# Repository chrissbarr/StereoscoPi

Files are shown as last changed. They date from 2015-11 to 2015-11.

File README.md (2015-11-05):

# StereoscoPi
StereoscoPi is a PCB that connects to a Raspberry Pi Compute Module. It powers the Compute Module, and provides connections for two cameras, along with a USB connection for a WiFi adaptor.

## Power
Power input is via a 2.1mm barrel jack. StereoscoPi uses a highly efficient switching regulator, and can accept 5V - 17V.

## Cameras
StereoscoPi is designed to work with the improved Raspberry Pi camera boards developed by [ArduCam](http://www.arducam.com/raspberry-pi-camera-rev-c-improves-optical-performance/). The connectors used are compatible with the standard Raspberry Pi camera boards, however the ArduCam boards are larger and feature different hole spacing.

## Connectivity
In order to minimise the size and weight of StereoscoPi, there is no onboard USB hub - this means only the single USB port integrated into the Broadcom SOC is available. This has been broken out to a full size USB-A socket.

Because the Raspberry Pi Compute module does not use removable storage as is the case with the other Raspberry Pi boards, it is necessary to connect the module to a computer and mount the flash memory as a mass storage device. This allows the copying over of all necessary operating system files. There is an onboard microUSB socket to facilitate this. As the Broadcom SOC only has the one USB connection, usually this connector is inactive. When the programming jumper is set appropriately, the full-size USB socket is disconnected, the microUSB socket is connected, and the board is set into programming mode.

Several additional outputs for power and PWM signals are broken out across the board. These are general purpose, but could - for example - be used to drive a small servo-based gimbal.

## Prototype
A proof-of-concept prototype has been constructed using two Raspberry Pi 2 B SBCs, and two separate wireless network adaptors. For information on replicating the hardware of this setup, follow the guide on the Prototype Hardware page. For software setup, see the Prototype Software page.

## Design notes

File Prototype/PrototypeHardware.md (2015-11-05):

# Prototype Hardware
## Electronics
### Bill of Materials
* 2x Raspberry Pi A+ / B+ / 2B
* 2x Raspberry Pi Camera Module (preferably [ArduCam](http://www.arducam.com/raspberry-pi-camera-rev-c-improves-optical-performance/) improved version)
* 2x SD / MicroSD Card to suit Pi
* 2x USB WiFi Adaptor
* 1x 2P-2P Female Jumper Cable

The system can be powered by a microUSB cable - just make sure your power source can do ~ 2A. A USB socket on a computer won't do, but most 'fast' phone charges should do the trick. If you want to use a battery (or other non-USB power source) you'll also need:
* 1x 5V Voltage Regulator, minimum 2A (Pololu have an excellent [module](https://www.pololu.com/product/2851) to suit 5V/5A, 7-38V Input)
* 1x Suitable Power Connector (I used an XT60 to pair with LiPo batteries I had on hand)

### Fritzing Diagram
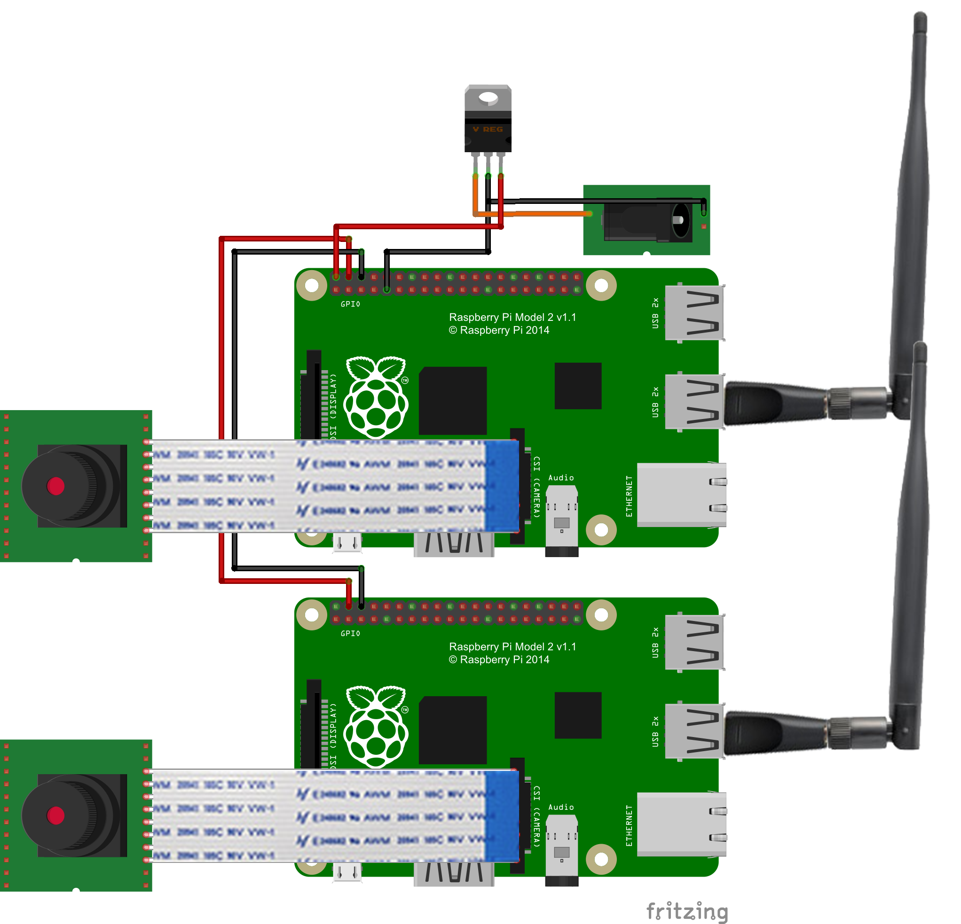
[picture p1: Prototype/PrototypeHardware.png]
Diagram This is the diagram


## Mechanical
A 3D-printable case has been designed to house two Raspberry Pi modules, and to mount two cameras at approximate eye spacing.

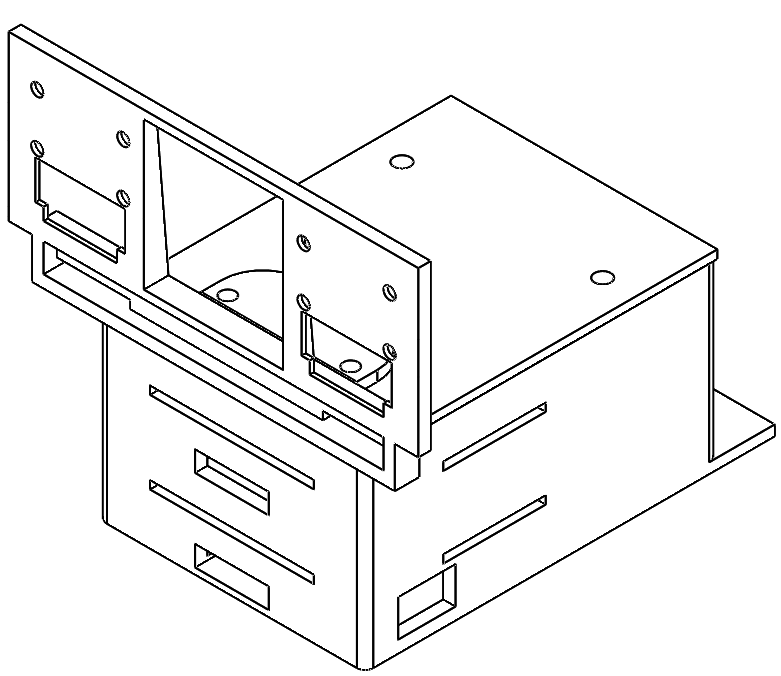
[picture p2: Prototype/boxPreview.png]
Case This is the case


The files for this case can be found in the CAD folder, with SolidWorks source files and STL files for printing.

The following files are required regardless of configuration:
* double-pi-box
* box-lid

Depending on camera choice, there are two files available:
* camera-bracket-arducam
* camera-bracket-standard

In addition to these printed parts, the following fixings are required:
* 8x M3 Standoff, 18mm
* 8x M3 Nut
* 4x M3x10 Bolt

The standard Raspberry Pi Camera modules require M2 mounting hardware:
* 8x M2x10 Bolt
* 8x M2 Nut

The Arducam Camera modules use M3 mounting hardware:
* 8x M3x10 Bolt
* 8x M3 Nut

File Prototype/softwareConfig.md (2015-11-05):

# Software Configuration
## Receiving Computer
This guide assumes you're running a recent version of Ubuntu. The StereoscoPi prototype software is written in Python, and should have good cross-platform compatibility. Likewise GStreamer supports most major operating systems - it should be possible to replicate this setup on Windows or OSX. For the sake of simplicity, we will use Ubuntu here.
### GStreamer Installation
First we need to tell our system where to look for the GStreamer framework:

`sudo add-apt-repository ppa:gstreamer-developers/ppa`

Update:

`sudo apt-get update`

Install GStreamer 1.0:

`sudo apt-get install gstreamer1.0*`

Test GStreamer is installed:

`gst-inspect-1.0 fakesrc`

If succesful, you should see something similar to the following:

```
Factory Details:
Rank                     none (0)
Long-name                Fake Source
Klass                    Source
...
...
...
Element Signals:
"handoff" :  void user_function (GstElement* object,
                                 GstBuffer* arg0,
                                 GstPad* arg1,
                                 gpointer user_data);
```

### Download StereoscoPi Scripts
Download the files in the 'Scripts' folder. You can either do this manually, by clicking each file, and clicking on 'Raw' then saving, or we can clone the needed files with Git.

Because we don't want to clone the whole repository, there are a few more steps than usual. First, make an empty folder to store the files in:

```
mkdir StereoscoPi
cd StereoscoPi
```

Now let's initialise git and clone the directory we want:

```
git init
git remote add -f origin https://github.com/chrissbarr/StereoscoPi.git
git config core.sparseCheckout true
echo "Prototype/Scripts/" >> .git/info/sparse-checkout
git pull origin master
```

Change into the 'Scripts' directory, and check that you have the files:

`cd Prototype/Scripts/`
`ls`

You should see the files (or similar):

```receiveStream.py      transmitStream.sh```

### Configuring receiveStream.py
The receiveStream.py script requires the following information:

* Screen Resolution (i.e. 1920x1080 for the Oculus DK2)
* Pi 1 Port (i.e. 5000)
* Pi 2 Port (i.e. 5001)

Edit the receiveStream.py file, and add these details in the 'Required Configuration' section near the top of the file, as shown:

```
# Required Configuration
display_width = 1920
display_height = 1080
port1 = '5001'
port2 = '5000'
```

## Transmitting Computer
You'll need to repeat this process for each Pi. First you'll need to configure each Pi for SSH access - Adafruit have a great tutorial for doing this [here](https://learn.adafruit.com/adafruits-raspberry-pi-lesson-6-using-ssh). Once you have SSH access set up, continue with the steps below.

### Install GStreamer
`sudo nano /etc/apt/sources.list`

Add the following line to the end of the file:

`deb http://vontaene.de/raspbian-updates/ . main`

CTRL+X, save the file over the original, and exit. Update:

`sudo apt-get update`

Download GStreamer:

`sudo apt-get install gstreamer1.0`

Just as we did on the receiving computer, test GStreamer is installed:

`gst-inspect-1.0 fakesrc`

If succesful, you should see something similar to the following:

```
Factory Details:
Rank                     none (0)
Long-name                Fake Source
Klass                    Source
...
...
...
Element Signals:
"handoff" :  void user_function (GstElement* object,
                                 GstBuffer* arg0,
                                 GstPad* arg1,
                                 gpointer user_data);
```

### Copy transmitStream.sh
When we downloaded the scripts to the receiving computer earlier, we downloaded the script we need to place on the Pi - transmitStream.sh. Assuming you're still in the 'Prototype/Scripts/' folder on the receiving computer, copy the file over SSH as follows:

`scp transmitStream.sh user@remote.host:/scripts`

On the Pi, check that the file is present. Alternatively, you can repeat the git process we used above, or copy the file across any other way you'd like.

## Running Software
### Running transmitStream.sh
First we need to run transmitStream.sh on each Pi. transmitStream.sh is really just a more convenient way of typing a rather long GStreamer command - namely:

`raspivid -t 999999 -w $WIDTH -h $HEIGHT -fps $FRAMERATE -rot 0 -b $BITRATE -n -pf baseline -md 5 -o - | gst-launch-1.0 -e -vvv fdsrc ! h264parse ! rtph264pay pt=96 config-interval=1 ! udpsink host=$TARGET_IP port=$PORT`

Connect via SSH. You can run the transmitStream.sh script as follows:

`bash transmitStream.sh 192.168.2.4 5000 1280 720 50 3000000`

Where the arguments represent the following:
* 192.168.2.4 - IP Address of the computer that will run receiveStream.py
* 5000 - Port that we want to transmit on. This needs to be different for each Pi - 5000 and 5001 are good numbers.
* 1280 and 720 - width and height, respectively, of video acquired from the attached camera
* 50 - video framerate
* 3000000 - bitrate the video is encoded at. Dependent on network conditions, decrease if video is jerky / high-latency, increase for higher quality.

When the script is running, the LED on the camera module should light up, indicating the camera is active.

### Running receiveStream.py
On the receiving computer, navigate to the folder containing receiveStream.py, and run the script:

`python receiveStream.py`

After a momentary delay, a full-screen application should appear. Video feeds from both Pi transmitters should appear, side-by-side. If nothing happens, check that:

* Both Pis are transmitting
* You're using the same port numbers in receiveStream.py and on each Pi to run transmitStream.sh
* All three computers are connected to the same network
* That the IP of the receiving computer is correctly set on each Pi in the call to transmitStream.sh

If the video appears, hurray! Check that the camera's aren't inverted (left is right, right is left, etc). If they are the wrong way around, exit receiveStream.py by pressing CTRL+C, and run it again, this time with the argument to swap the cameras around:

`python receiveStream.py -sw 1`

If you can only get one camera transmitting, or want to run monoscopically, you can call receiveStream.py as:

`python receiveStream.py -s 1`

Which will cause the program to only look for the first camera specified, and duplicate it twice, side-by-side. If you want to run only the second camera, swap the cameras:

`python receiveStream.py -sw 1 -s 1`

The default video scale should fill up as much of the screen as it can without distorting or overlapping the video feeds. If you'd like to adjust the scale, you can do so:

`python receiveStream.py -scale 80`

This will run each video feed at 80%. Smaller values will appear equivelant to using a smaller FOV headset.

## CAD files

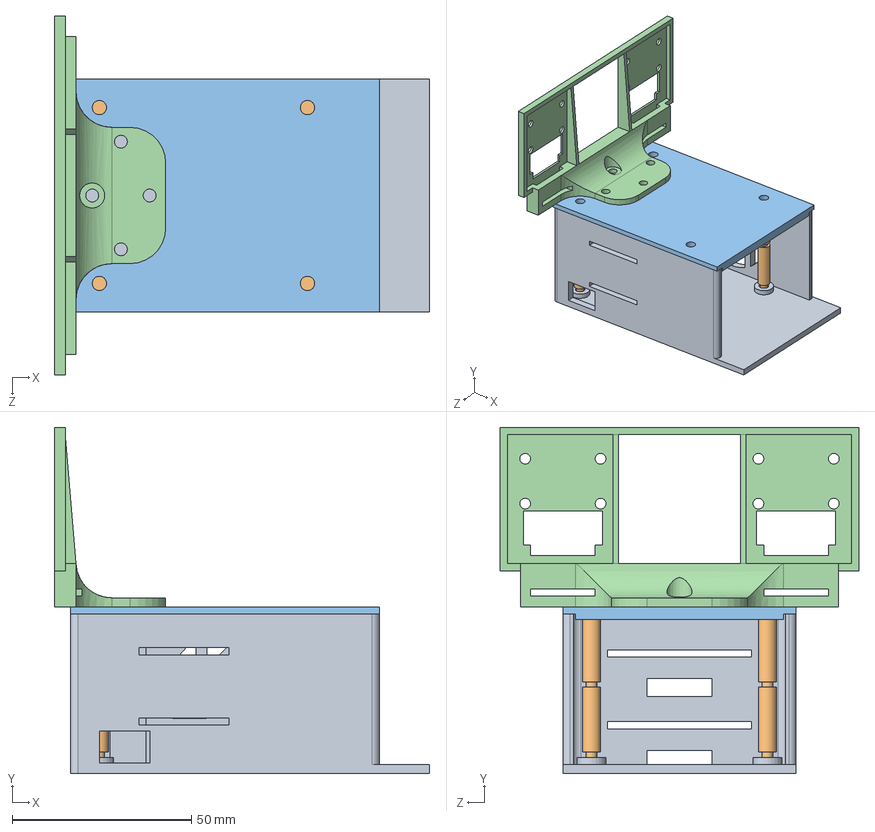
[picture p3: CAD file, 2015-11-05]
Prototype/CAD/test-assembly.SLDASM
104.5 x 96.5 x 100.0 mm
double-pi-box
18mm-standoff x 8
box-lid
camera-bracket-standard

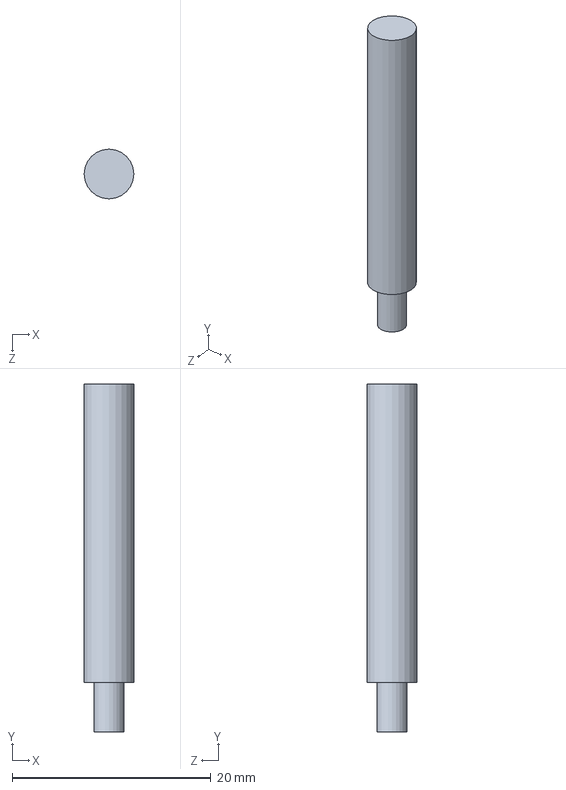
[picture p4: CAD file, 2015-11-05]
Prototype/CAD/30mm-standoff.SLDPRT
5.00 x 35.0 x 5.00 mm

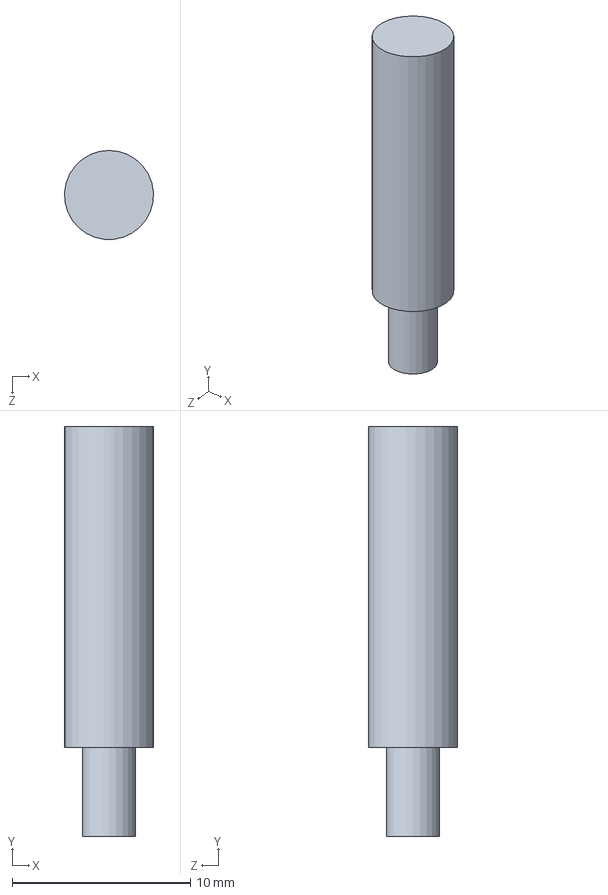
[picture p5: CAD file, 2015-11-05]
Prototype/CAD/18mm-standoff.SLDPRT
4.99 x 23.0 x 5.00 mm

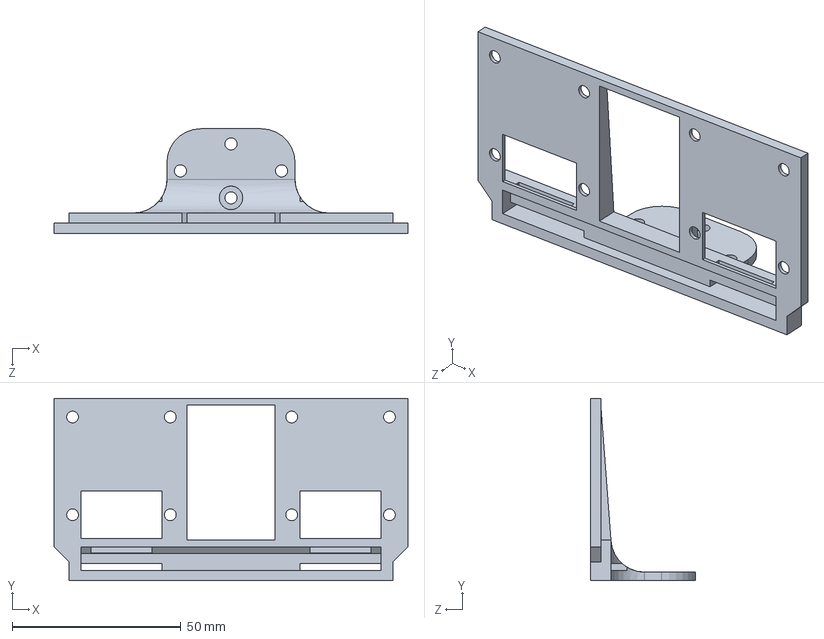
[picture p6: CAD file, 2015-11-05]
Prototype/CAD/camera-bracket-arducam.SLDPRT
105.0 x 54.0 x 31.0 mm

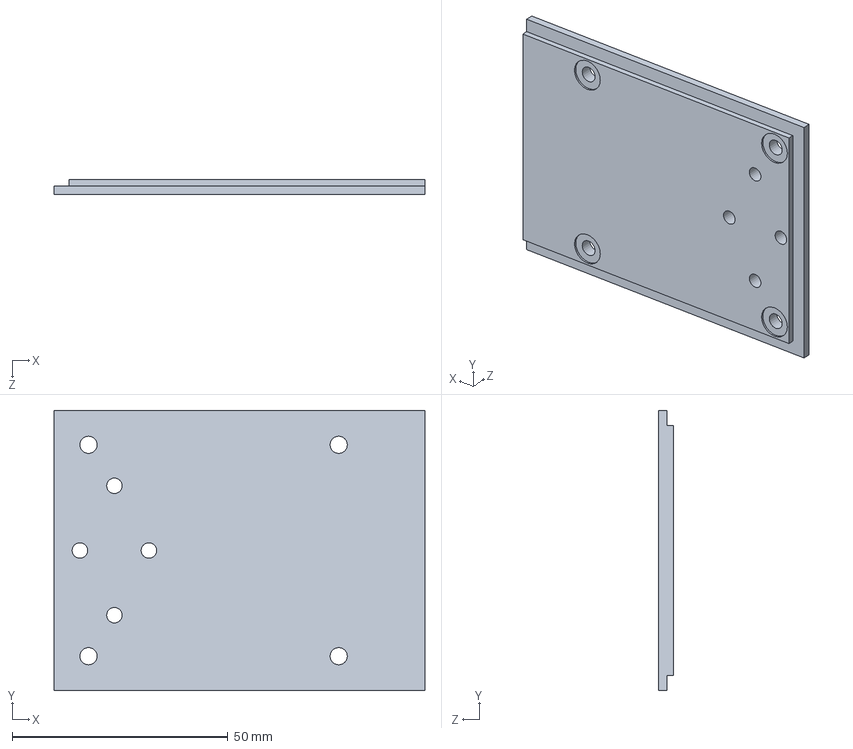
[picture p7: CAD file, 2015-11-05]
Prototype/CAD/box-lid.sldprt
86.0 x 65.0 x 3.50 mm

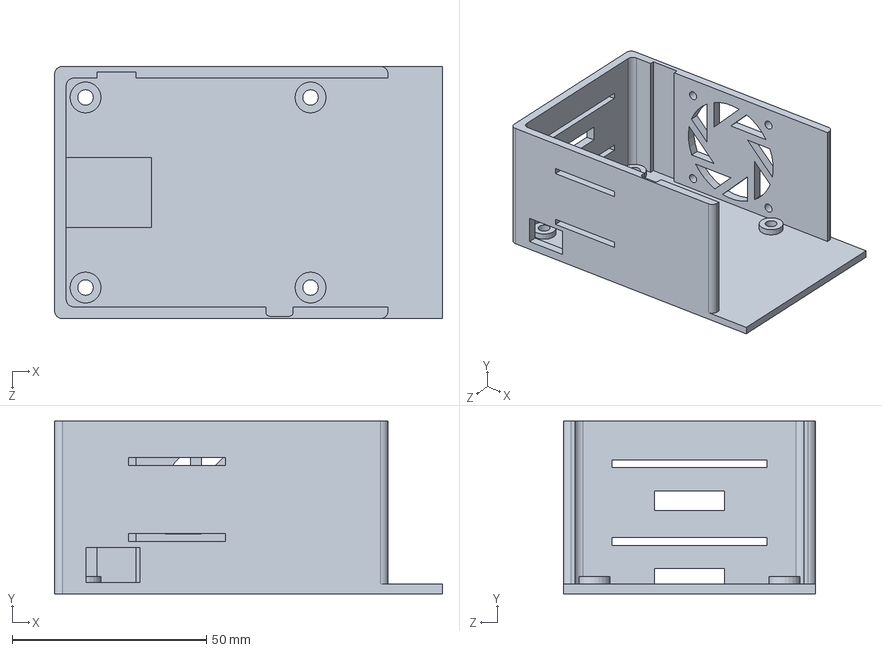
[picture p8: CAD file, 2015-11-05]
Prototype/CAD/double-pi-box.SLDPRT
100.0 x 44.5 x 65.0 mm

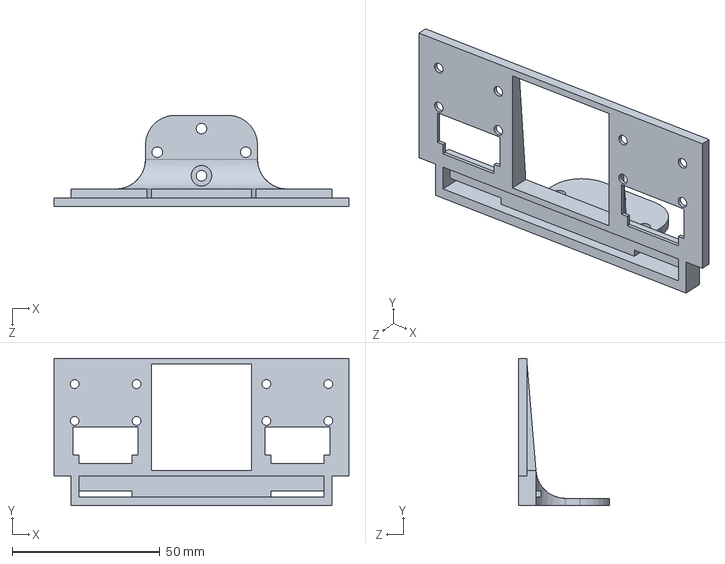
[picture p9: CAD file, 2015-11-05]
Prototype/CAD/camera-bracket-standard.SLDPRT
100.0 x 50.0 x 31.0 mm

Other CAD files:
Prototype/CAD/box-lid.STL
Prototype/CAD/camera-bracket-arducam.STL
Prototype/CAD/camera-bracket-standard.STL
Prototype/CAD/double-pi-box.STL

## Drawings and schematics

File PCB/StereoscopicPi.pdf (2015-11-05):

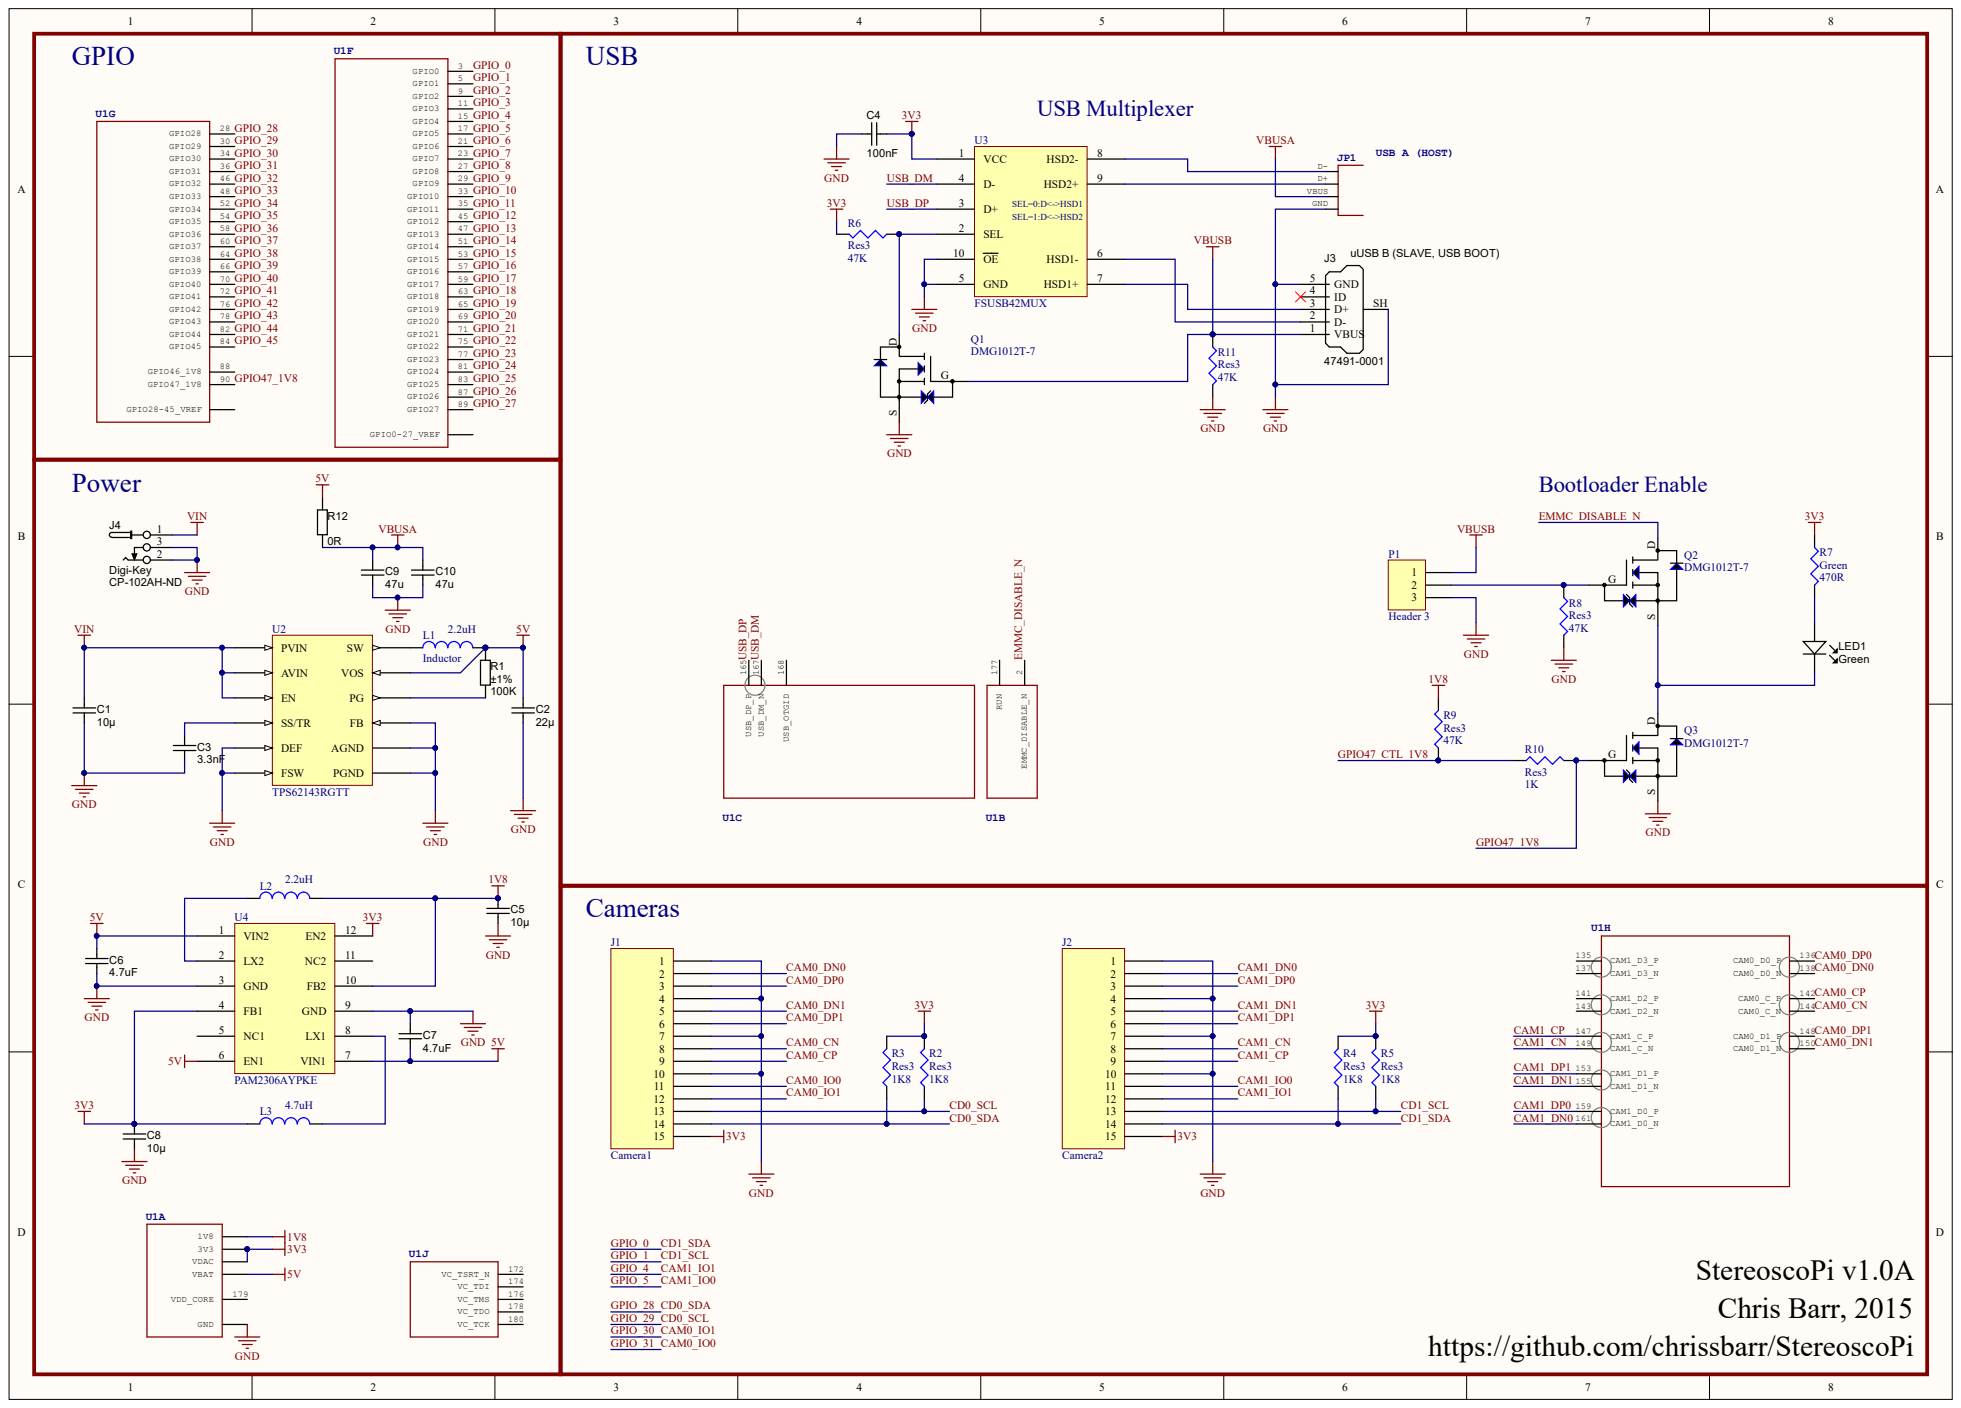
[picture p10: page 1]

https://github.com/chrissbarr/StereoscoP

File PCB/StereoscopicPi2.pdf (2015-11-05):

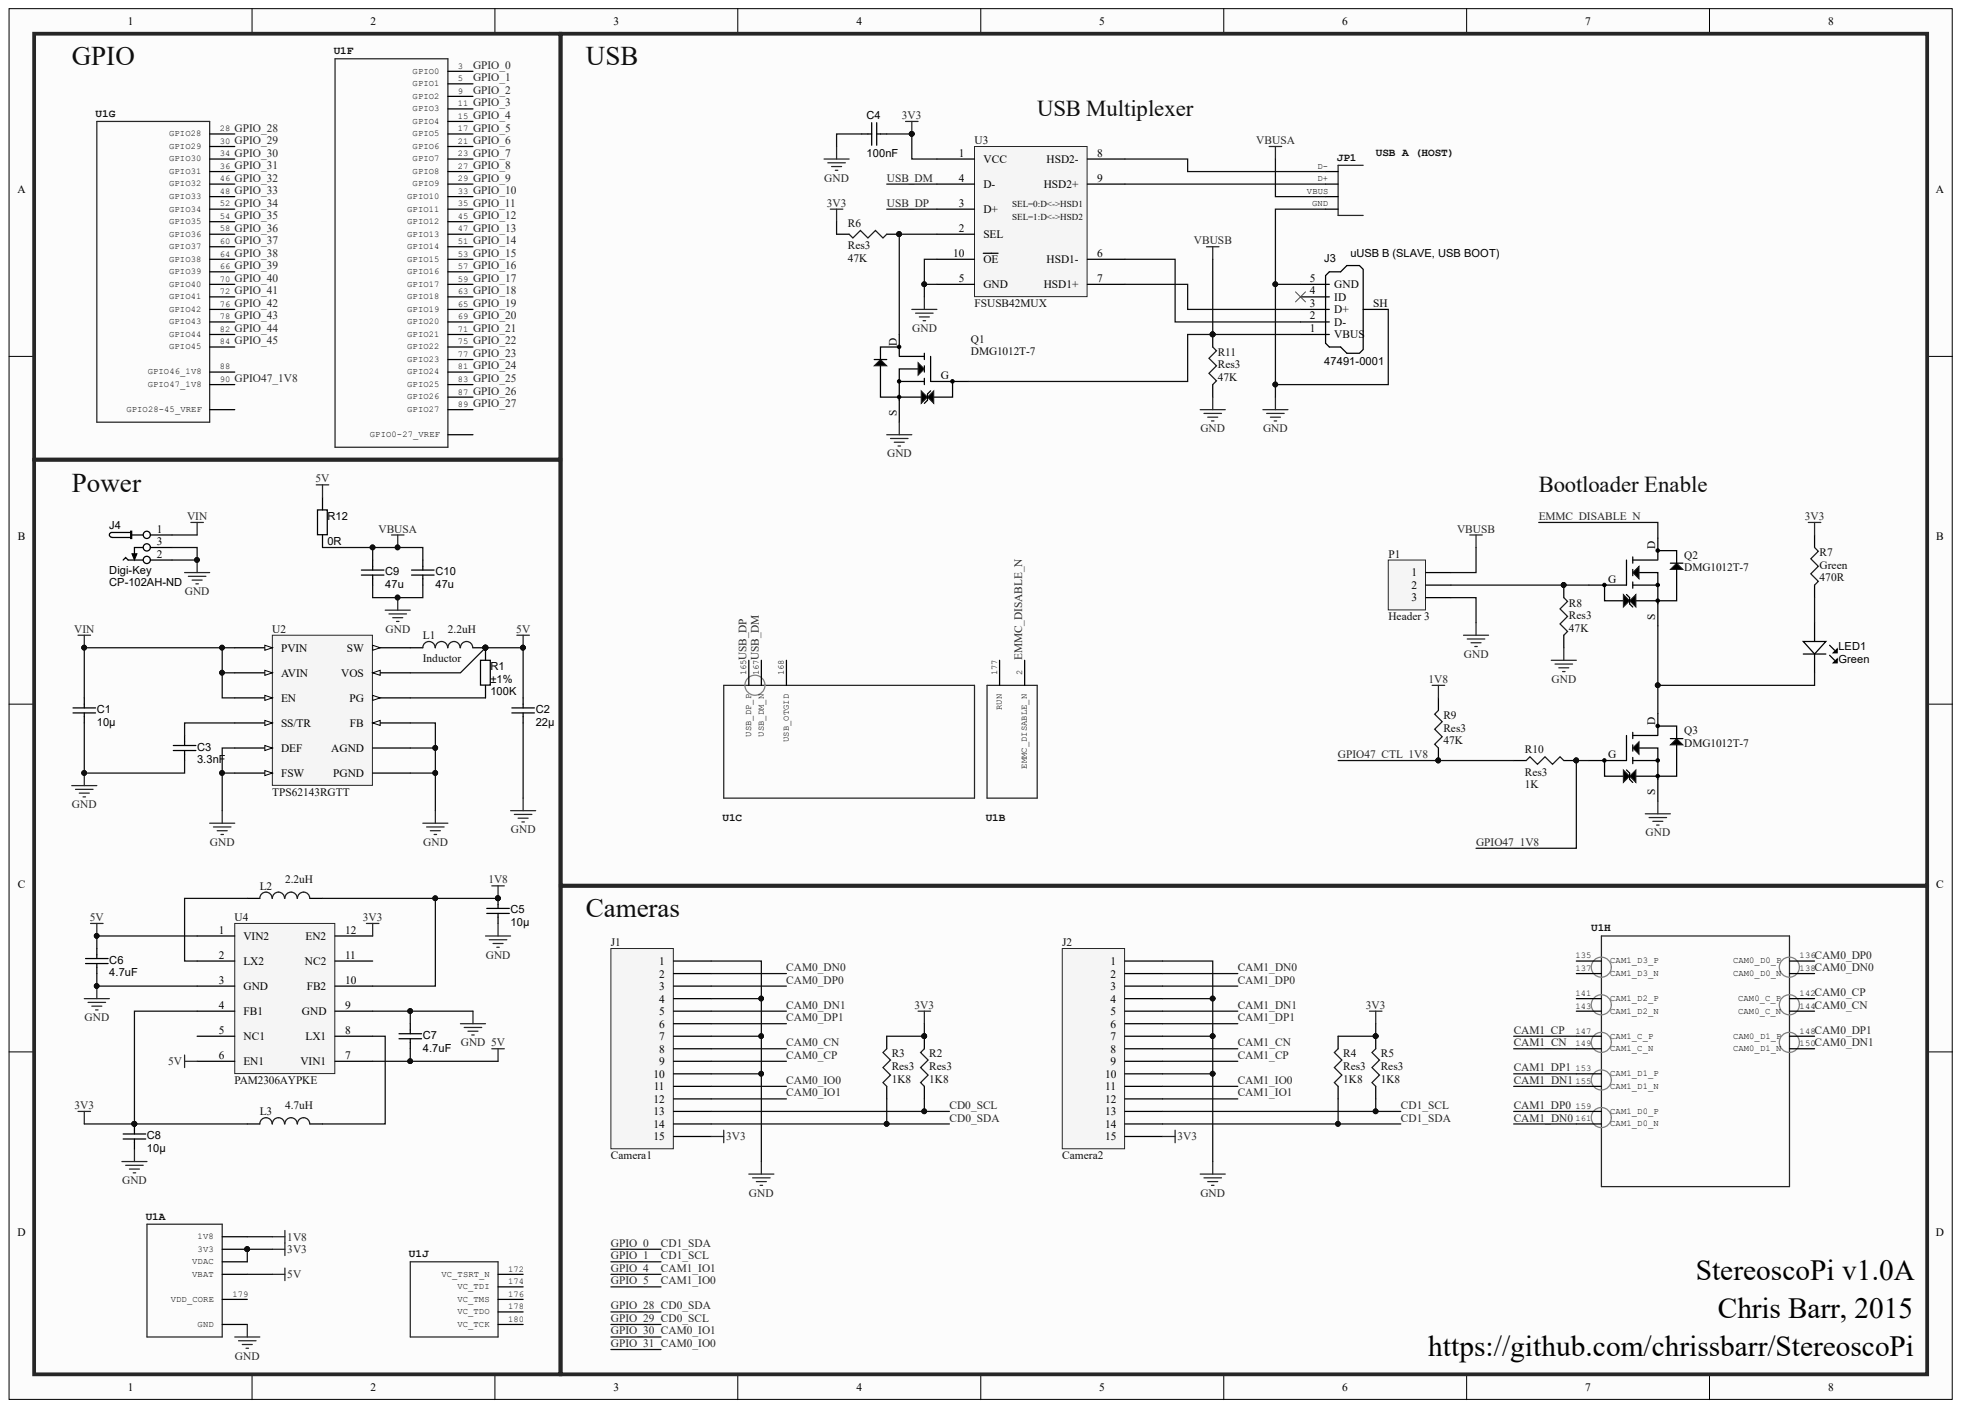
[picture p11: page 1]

https://github.com/chrissbarr/StereoscoPi

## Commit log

2015-09-29 Push initial design
    Mostly fleshed out
    [StereoscopicPi.PrjPcb, StereoscopicPi.SchDoc, stereoscopicPi.PcbDoc]
2015-09-29 Finished Routing
    [StereoscopicPi.SchDoc]
2015-11-05 Tidied Schematic
    [StereoscopicPi.SchDoc]
2015-11-05 Prototype Hardware Fritzing Diagram
2015-11-05 Restructure Folders
    [StereoscopicPi.PrjPcb, StereoscopicPi.SchDoc]
2015-11-05 Added Case
    Added files for printed prototype case, added instructions.
    [18mm-standoff.SLDPRT, 30mm-standoff.SLDPRT, box-lid.STL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]
